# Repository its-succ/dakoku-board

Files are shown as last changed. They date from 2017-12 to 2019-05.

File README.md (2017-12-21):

# dakoku-board

これは勤怠の出社/退社をサーバーに送信するためのマイコンボードプログラムです。

## ハードウェア

- [ESPr Developer](https://www.switch-science.com/catalog/2500/)
- [FeliCa リーダー・ライター RC-S620S](https://www.switch-science.com/catalog/353/)
- [FeliCa Plug ピッチ変換基板](https://www.switch-science.com/catalog/1030/)
- [I2C接続の小型LCD搭載ボード(3.3V版)](https://www.switch-science.com/catalog/1405/)

## 開発環境

- Arduino IDE 1.6.12 以上
- Fritzing

ESPr Developer を Arduino IDE から利用する方法は、スイッチサイエンスの[ESP-WROOM-02開発ボードをArduino IDEで開発する方法](http://trac.switch-science.com/wiki/esp_dev_arduino_ide)を参照してください。

### EspSoftwareSerial ライブラリ

また、Felicaの接続に [EspSoftwareSerial](https://github.com/plerup/espsoftwareserial) を使っています。
上記でインストールされた ESPr ボードの中にも含まれているのですが、少し古いので新しいバージョンを利用します。

1. Githubのページ右上の「Clone or download」から「Download ZIP」を選んでZIPファイルをダウンロード
1. Arduino IDEを起動
1. 「スケッチ」メニューの「ライブラリをインクルード」→「.ZIP形式のライブラリをインストール…」でダウンロードしたZIPファイルを選択

また、このままだとライブラリがコンフリクトするので、ボードライブラリに同梱されている古いものを削除します。

```
$ rm -rf ~/Library/Arduino15/packages/esp8266/hardware/esp8266/2.3.0/libraries/SoftwareSerial
```

少しディレクトリ名が違うかもしれないので、コンパイル時にコンフリクトエラーが発生したディレクトリで `/esp8266/hardware/esp8266/2.3.0/libraries` の方を削除してください

### I2CLiquidCrystal ライブラリ

Arduinoでは `LiquidCrystal` というライブラリでLCDの制御ができますが、これはI2C接続に対応していないので [ストロベリー・リナックス/秋月電子のI2C液晶/OLEDほかをArduinoで使う](http://n.mtng.org/ele/arduino/i2c.html) というサイトで公開されている `I2CLiquidCrystal` ライブラリを利用します。

サイト下部の `ファイル` から最新版を取得し、EspSoftwareSerial と同様に「.ZIP形式のライブラリをインストール」を実行してください。

## 回路イメージ

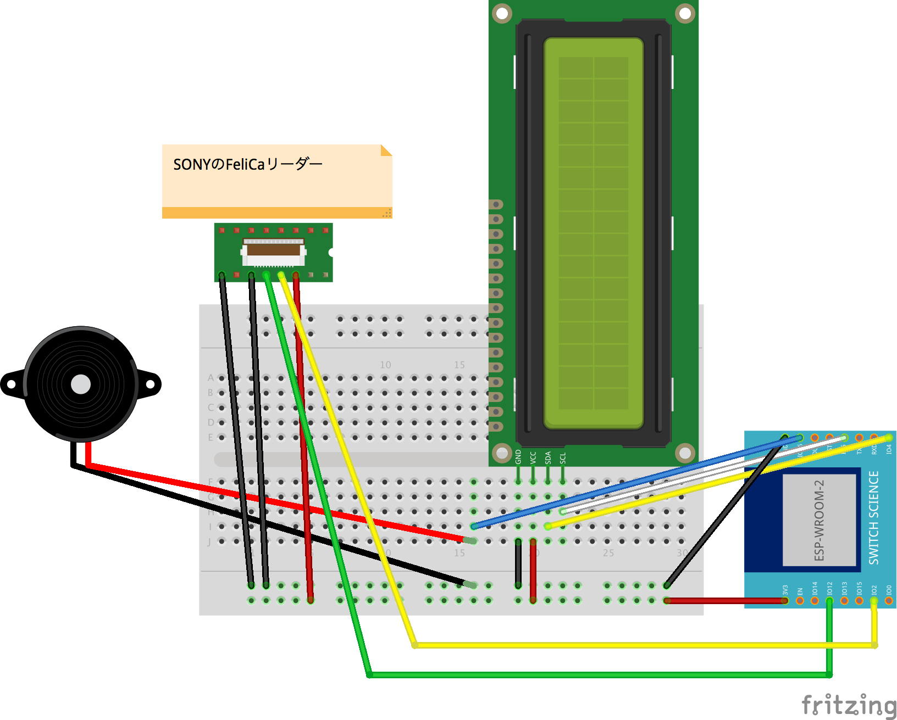
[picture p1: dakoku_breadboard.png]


- 8x2 のLCD部品がなかったので、 16x2 の部品を使っています
- FeliCa Plug ピッチ変換基板 もなかったので、一般のFCCコネクタ部品を使っています

## 環境設定

`config.h.example` を `config.h` にコピーして、WIFIの設定を変更してください。

## TODO

WiFi環境でない場所でも使えるように、[Wio LTE](https://soracom.jp/products/wio_lte/) でも利用可能にする

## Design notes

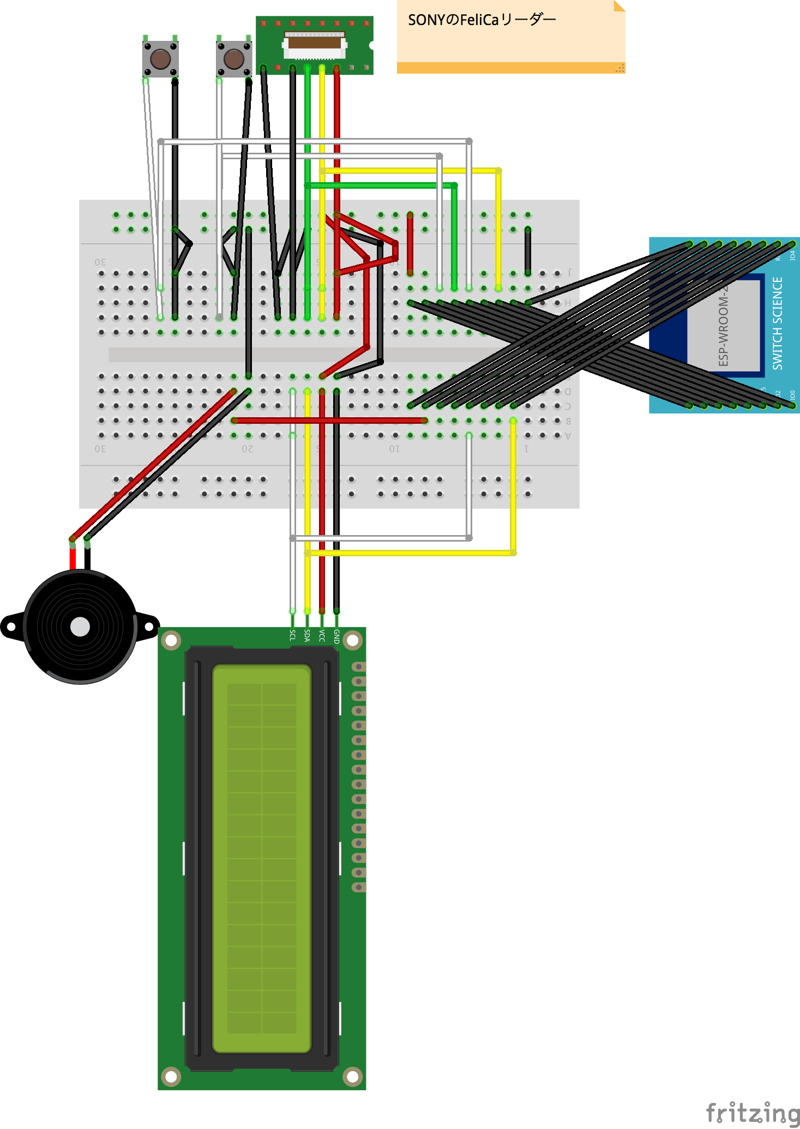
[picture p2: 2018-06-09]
dakoku-board-production.png

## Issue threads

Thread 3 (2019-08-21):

M5Stack + 3G 拡張ボード を使ったデバイスを作成する

sizuhiko, 2019-08-21:
- M5Stack Basic
  - すでにIoT Studyで購入済み
- [3G 拡張ボード](https://soracom.jp/products/kit/3g_module_m5stack/)
  - 個人的に購入済み。SIMもある（はず）
- FeliCa リーダー・ライター RC-S620S
  - すでにIoT Studyで購入済み（プロトで1つ使ったけど、まだ1つ余っているはず

sizuhiko, 2019-08-21:
うまく制作できたら、3G拡張ボードを経費で購入するとか検討
SIMの運用費とかどうするかなども含め

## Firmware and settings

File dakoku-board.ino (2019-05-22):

#include <Arduino.h>
#include <WiFiClientSecure.h>
#include <ESP8266WiFi.h>
#include "RCS620S.h"

#include <I2CLiquidCrystal.h>
#include <Wire.h>
#include <CloudIoTCore.h>

#include "config.h"
#include "esp8266_mqtt.h"

#define COMMAND_TIMEOUT 400
#define POLLING_INTERVAL 100
#define BEAT 300
#define JST  3600*9

static const int PiezoPin = 16;        // for Speaker
static const int ArriveButtonPin = 14; // for pushing when arrive at work
static const int LeaveButtonPin = 13;  // for pushing when leave work at  

RCS620S rcs620s;
String idm;

I2CLiquidCrystal lcd(20, (bool)false);

void setup() { 
  int ret;

  Serial.begin(115200);      // for RC-S620/S

  // ESP8266 WiFi setup
  netClient = new WiFiClientSecure();

  WiFi.mode(WIFI_STA);
  WiFi.begin(WIFI_SID, WIFI_PASSWORD);
  Serial.print("WiFi connecting");

  while (WiFi.status() != WL_CONNECTED) {
    delay(100);
  }

  Serial.println(" connected"); 
//  configTime(JST, 0, "ntp.nict.jp", "ntp.jst.mfeed.ad.jp");
  configTime(0, 0, "pool.ntp.org", "time.nist.gov");
  Serial.println("Waiting on time sync...");
  while (time(nullptr) < 1510644967) {
    delay(10);
  }

  // initialize RC-S620/S
  ret = rcs620s.initDevice();
  Serial.println("RCS620S: " + String(ret));
  while (!ret) {}             // blocking
  Serial.println("INIT"); 
  
  pinMode(ArriveButtonPin, INPUT_PULLUP);
  pinMode(LeaveButtonPin, INPUT_PULLUP);

  // set up the LCD's number of columns and rows: 
  initLCD();

  // Creates globals for MQTT
  setupCloudIoT();
}

void loop() {

  if (digitalRead(ArriveButtonPin) == LOW) {
    Serial.println("出社");
    
      tone(PiezoPin, 2000, 100); // 3番ピンに接続されたスピーカーを2000Hzで鳴らす
      delay(100);    // 100ms(1秒)待つ
      tone(PiezoPin, 1000, 100); // 3番ピンに接続されたスピーカーを1000Hzで鳴らす
      delay(100);    // 100ms(1秒)待つ

    lcd.setCursor(0, 0);
    lcd.kana("ｼｭｯｼｬ   ");
    lcd.setCursor(0, 1);
    lcd.print("        ");
    sendIoTCore("enter");
    delay(2000);
    initLCD();
  }
  if (digitalRead(LeaveButtonPin) == LOW) {
    Serial.println("退社");
    tone(PiezoPin, 880, 500);
    lcd.setCursor(0, 0);
    lcd.kana("ﾀｲｼｬ    ");
    lcd.setCursor(0, 1);
    lcd.print("        ");
    sendIoTCore("exit");
    delay(2000);
    initLCD();
  }

  // Polling
  rcs620s.timeout = COMMAND_TIMEOUT;
  int ret = rcs620s.polling();

  if(ret) {
    tone(PiezoPin, 3520, 300);
    char buf[9];
    sprintf(buf, "%02x%02x%02x%02x%02x%02x%02x%02x", rcs620s.idm[0], rcs620s.idm[1], rcs620s.idm[2], rcs620s.idm[3], rcs620s.idm[4], rcs620s.idm[5], rcs620s.idm[6], rcs620s.idm[7]);
    idm = String(buf);
    Serial.println("IDM:" + idm);
    for (int i = 0; i < 16; i++) {
      lcd.setCursor((int)i % 8, (int)i / 8);
      lcd.print(String(buf[i]));
    }
    delay(500);
  }

  rcs620s.rfOff();
  delay(POLLING_INTERVAL);
}

void initLCD() {
  lcd.begin(8, 2);
  lcd.print("PLEASE  ");
  lcd.setCursor(0, 1);
  lcd.print("TOUCH ! ");
}

void sendIoTCore(String action) {
  mqttClient->loop();
  delay(10);  // <- fixes some issues with WiFi stability

  if (!mqttClient->connected()) {
    connect();
  }

  publishTelemetry("{\"cardNumber\": \"" + idm + "\", \"action\": \"" + action + "\", \"device\": \"" + device_id + "\"}");
}

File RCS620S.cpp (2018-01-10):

/*
 * RC-S620/S sample library for Arduino
 *
 * Copyright 2010 Sony Corporation
 */

#include <stdio.h>
#include <string.h>
#include <inttypes.h>
#include <Arduino.h>
#include <Print.h>
#include <SoftwareSerial.h>

#include "RCS620S.h"

/* --------------------------------
 * Constant
 * -------------------------------- */

#define RCS620S_DEFAULT_TIMEOUT  1000

/* --------------------------------
 * Variable
 * -------------------------------- */

/* --------------------------------
 * Prototype Declaration
 * -------------------------------- */

/* --------------------------------
 * Macro
 * -------------------------------- */
static const int RXPin = 12, TXPin = 2;
SoftwareSerial ss(RXPin, TXPin, false, 256);

/* --------------------------------
 * Function
 * -------------------------------- */

/* ------------------------
 * public
 * ------------------------ */

RCS620S::RCS620S()
{
    this->timeout = RCS620S_DEFAULT_TIMEOUT;
}

int RCS620S::initDevice(void)
{
    int ret;
    uint8_t response[RCS620S_MAX_RW_RESPONSE_LEN];
    uint16_t responseLen;

    ss.begin(115200);

    /* RFConfiguration (various timings) */
    ret = rwCommand((const uint8_t*)"\xd4\x32\x02\x00\x00\x00", 6,
                    response, &responseLen);
    if (!ret || (responseLen != 2) ||
        (memcmp(response, "\xd5\x33", 2) != 0)) {
          Serial.println("ERROR1" + String(ret) + ":" + String(responseLen));
        return 0;
    }

    /* RFConfiguration (max retries) */
    ret = rwCommand((const uint8_t*)"\xd4\x32\x05\x00\x00\x00", 6,
                    response, &responseLen);
    if (!ret || (responseLen != 2) ||
        (memcmp(response, "\xd5\x33", 2) != 0)) {
          Serial.println("ERROR2");
        return 0;
    }

    /* RFConfiguration (additional wait time = 24ms) */
    ret = rwCommand((const uint8_t*)"\xd4\x32\x81\xb7", 4,
                    response, &responseLen);
    if (!ret || (responseLen != 2) ||
        (memcmp(response, "\xd5\x33", 2) != 0)) {
          Serial.println("ERROR3");
        return 0;
    }

    return 1;
}

int RCS620S::polling(uint16_t systemCode)
{
    int ret;
    uint8_t buf[9];
    uint8_t response[RCS620S_MAX_RW_RESPONSE_LEN];
    uint16_t responseLen;

    /* InListPassiveTarget */
    memcpy(buf, "\xd4\x4a\x01\x01\x00\xff\xff\x00\x00", 9);
    buf[5] = (uint8_t)((systemCode >> 8) & 0xff);
    buf[6] = (uint8_t)((systemCode >> 0) & 0xff);

    ret = rwCommand(buf, 9, response, &responseLen);
    if (!ret || (responseLen != 22) ||
        (memcmp(response, "\xd5\x4b\x01\x01\x12\x01", 6) != 0)) {
        return 0;
    }

    memcpy(this->idm, response + 6, 8);
    memcpy(this->pmm, response + 14, 8);

    return 1;
}

int RCS620S::cardCommand(
    const uint8_t* command,
    uint8_t commandLen,
    uint8_t response[RCS620S_MAX_CARD_RESPONSE_LEN],
    uint8_t* responseLen)
{
    int ret;
    uint16_t commandTimeout;
    uint8_t buf[RCS620S_MAX_RW_RESPONSE_LEN];
    uint16_t len;

    if (this->timeout >= (0x10000 / 2)) {
        commandTimeout = 0xffff;
    } else {
        commandTimeout = (uint16_t)(this->timeout * 2);
    }

    /* CommunicateThruEX */
    buf[0] = 0xd4;
    buf[1] = 0xa0;
    buf[2] = (uint8_t)((commandTimeout >> 0) & 0xff);
    buf[3] = (uint8_t)((commandTimeout >> 8) & 0xff);
    buf[4] = (uint8_t)(commandLen + 1);
    memcpy(buf + 5, command, commandLen);

    ret = rwCommand(buf, 5 + commandLen, buf, &len);
    if (!ret || (len < 4) ||
        (buf[0] != 0xd5) || (buf[1] != 0xa1) || (buf[2] != 0x00) ||
        (len != (3 + buf[3]))) {
        return 0;
    }

    *responseLen = (uint8_t)(buf[3] - 1);
    memcpy(response, buf + 4, *responseLen);

    return 1;
}

int RCS620S::rfOff(void)
{
    int ret;
    uint8_t response[RCS620S_MAX_RW_RESPONSE_LEN];
    uint16_t responseLen;

    /* RFConfiguration (RF field) */
    ret = rwCommand((const uint8_t*)"\xd4\x32\x01\x00", 4,
                    response, &responseLen);
    if (!ret || (responseLen != 2) ||
        (memcmp(response, "\xd5\x33", 2) != 0)) {
        return 0;
    }

    return 1;
}

int RCS620S::push(
    const uint8_t* data,
    uint8_t dataLen)
{
    int ret;
    uint8_t buf[RCS620S_MAX_CARD_RESPONSE_LEN];
    uint8_t responseLen;

    if (dataLen > 224) {
        return 0;
    }

    /* Push */
    buf[0] = 0xb0;
    memcpy(buf + 1, this->idm, 8);
    buf[9] = dataLen;
    memcpy(buf + 10, data, dataLen);

    ret = cardCommand(buf, 10 + dataLen, buf, &responseLen);
    if (!ret || (responseLen != 10) || (buf[0] != 0xb1) ||
        (memcmp(buf + 1, this->idm, 8) != 0) || (buf[9] != dataLen)) {
        return 0;
    }

    buf[0] = 0xa4;
    memcpy(buf + 1, this->idm, 8);
    buf[9] = 0x00;

    ret = cardCommand(buf, 10, buf, &responseLen);
    if (!ret || (responseLen != 10) || (buf[0] != 0xa5) ||
        (memcmp(buf + 1, this->idm, 8) != 0) || (buf[9] != 0x00)) {
        return 0;
    }

    delay(1000);

    return 1;
}

/* ------------------------
 * private
 * ------------------------ */
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

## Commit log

2017-12-21 必要なライブラリの導入方法を追記
2018-01-10 スピーカーとボタンを追加した
    [dakoku-board.fzz]
2018-06-09 full package
    [dakoku-board-production.fzz, dakoku-board.fzz]
2019-05-22 デバイスから打刻できるようにした
